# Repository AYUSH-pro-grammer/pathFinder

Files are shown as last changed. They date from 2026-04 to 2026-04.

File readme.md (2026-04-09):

# Pathfinder – Tiny Reaction Game!

Hello!! 
This is my Hack Club Stasis project  its based on reaction time and a bit of fun

---

## How It Works

- LEDs blink
- You press buttons 
- Turn the knob
- Try to react FAST!!

### Rules:
- Press button 1 -> led 1 lights up 
- Press button 2 -> quickly after btn1 -> builds combo both will get on
- if you press button 2 quickly and multiple times then led2 turns on
- Too slow? nothing happens

---

## Images

### 3D View
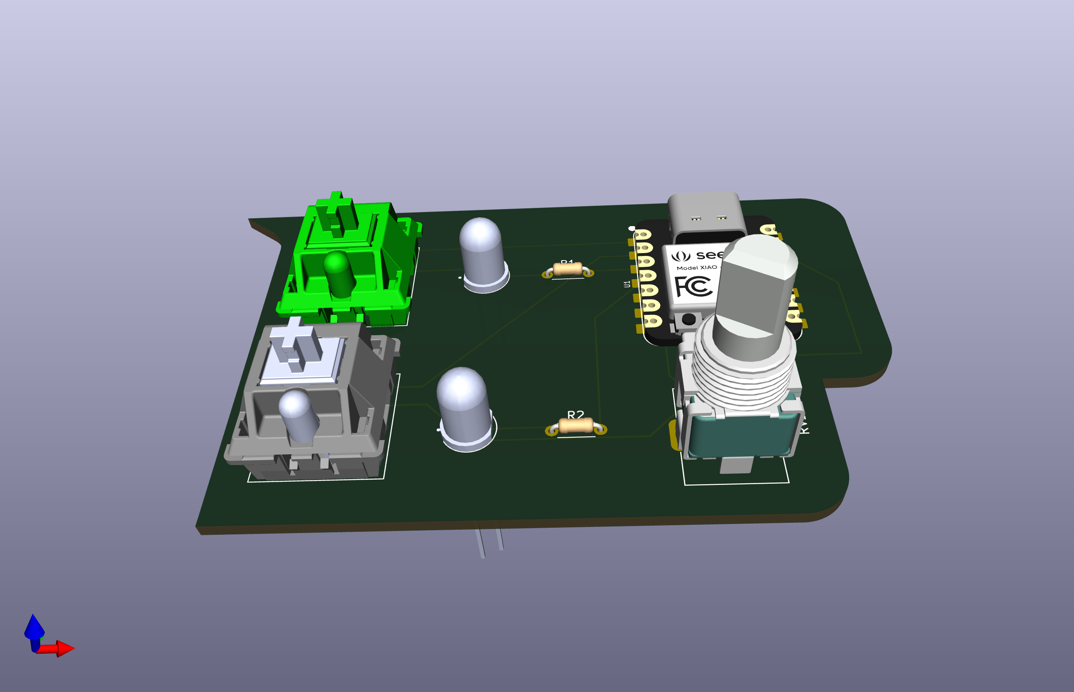
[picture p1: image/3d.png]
3D


### Circuit
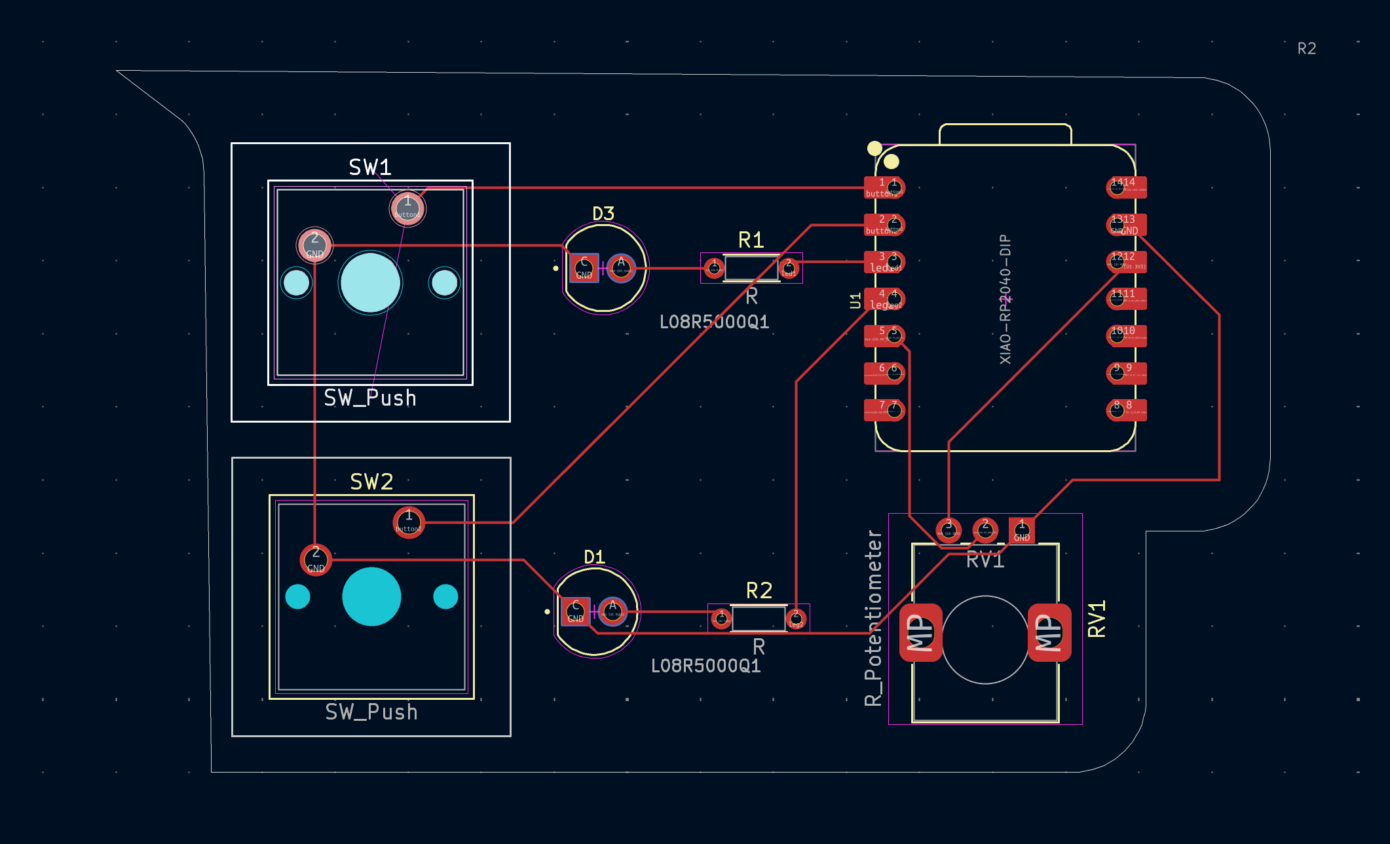
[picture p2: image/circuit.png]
Circuit


### Schematic
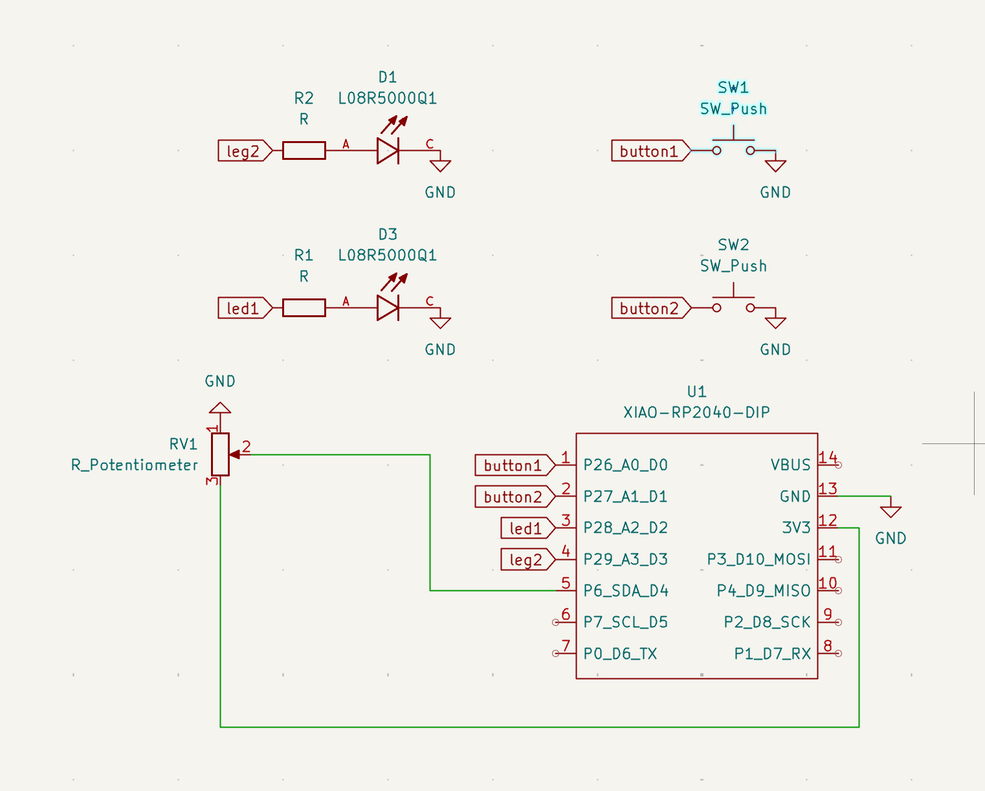
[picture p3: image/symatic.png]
Schematic


---

## Components

- LEDs 
- Resistors 
- Xiao RP2040 
- Cherry MX switches 
- PCB 
- Potentiometer (knob!!) 

---

## Code

```cpp
int btn1 = D0;
int btn2 = D1;
int led1 = D2;
int led2 = D3;

int potentio = D4;

long btn2cnt = 0;
long button1time = 0;
long button2time = 0;

void setup() {
  pinMode(btn1, INPUT_PULLUP);
  pinMode(btn2, INPUT_PULLUP);
  pinMode(potentio, INPUT);

  pinMode(led1, OUTPUT);
  pinMode(led2, OUTPUT);
}

void loop() {

  int pot_reading = analogRead(potentio);
  int brightness = map(pot_reading, 0, 1023, 0, 255);

  if (digitalRead(btn1) == LOW) {
    button1time = millis();
    analogWrite(led1, brightness);
  } else {
    analogWrite(led1, 0);
  }

  if (digitalRead(btn2) == LOW) {
    button2time = millis();
    btn2cnt += 1;
  }

  if (abs(button1time - button2time) <= 1000) {
    if (btn2cnt > 2) {
      analogWrite(led2, brightness);
      btn2cnt = 0;
    }
  } else {
    analogWrite(led2, 0);
  }
}

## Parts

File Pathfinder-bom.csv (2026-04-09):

Name | Purpose | Quantity | Total Cost (USD) | Link | Distributor
pcb | the main board where all compoents connects | 1 | 8.11 | https://jlcpcb.com/ | jlcpcb
LED Indication | it will glow | 2 | 0.10 | https://robu.in/product/tj-l5fytghgmcgsflc2g-a5-togialed-20ma-foggy-green-lens-20%e2%84%8380%e2%84%83-emerald-45-5mm-round-lamp-head-2-8v3-6v-plugind5mm-led-i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 | robu
Potentiometers | to increase and decrease the brightness of lights | 1 | 0.62 | https://robu.in/product/rk09k1130a5r-alpsalpine-%c2%b120-10k%cf%89-plugin-potentiometers-variable-resistors-rohs/ | robu
Seeed Studio XIAO RP2040 v1.0 | microcontroller controllers code | 1 | 7.00 | https://robu.in/product/seeed-studio-xiao-rp2040-v1-0/ | robu
Gateron Milky PRO Switch – 5pin | to send input to microcontroller | 1 | 3.50 | https://meckeys.com/cart/ | meckeys

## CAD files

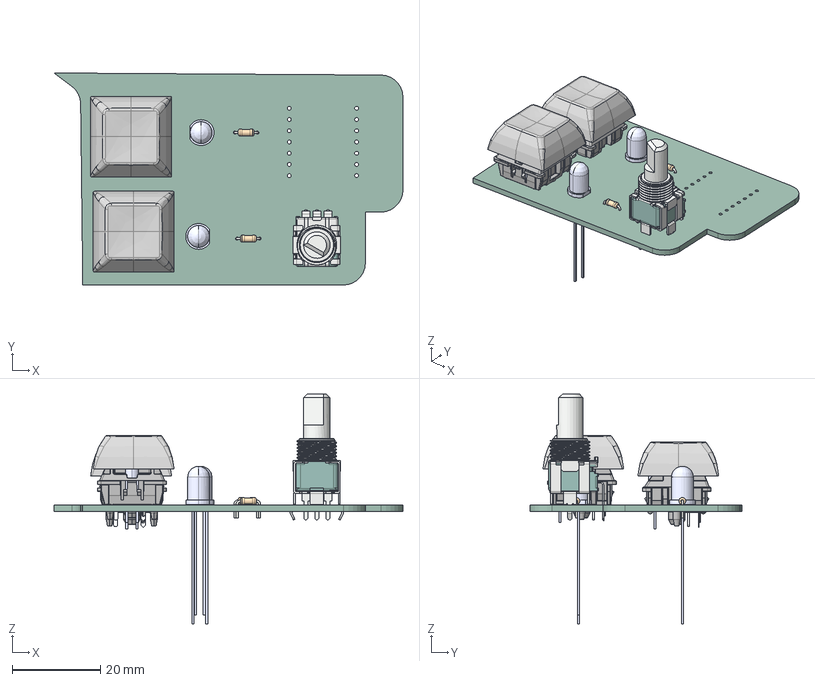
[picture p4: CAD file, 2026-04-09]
pathFinder.step
79.0 x 48.0 x 52.0 mm
RK09L1140-F15-C0
MX Öá °´¼ü¡ä_¨¹___¡§1 x 2
MX ס סͥ¨¢¨¬_¡§¡顧__ x 2
MXס ϞñLEDLEDLED x 2
MXÖá ÖáÌå µ×²¿ ¦Ì¡Á2__Ä¬ÈÏ_¨¢2____¨¨_ x 2
֫½ğ__Ĭɏ__¨¨_ x 2
DSA_Keycap_CherryMX x 2
R_Axial_DIN0204_L3.6mm_D1.6mm_P5.08mm_Horizontal x 2
Blue_LED_5mm_STEP x 2
pathFinder_PCB

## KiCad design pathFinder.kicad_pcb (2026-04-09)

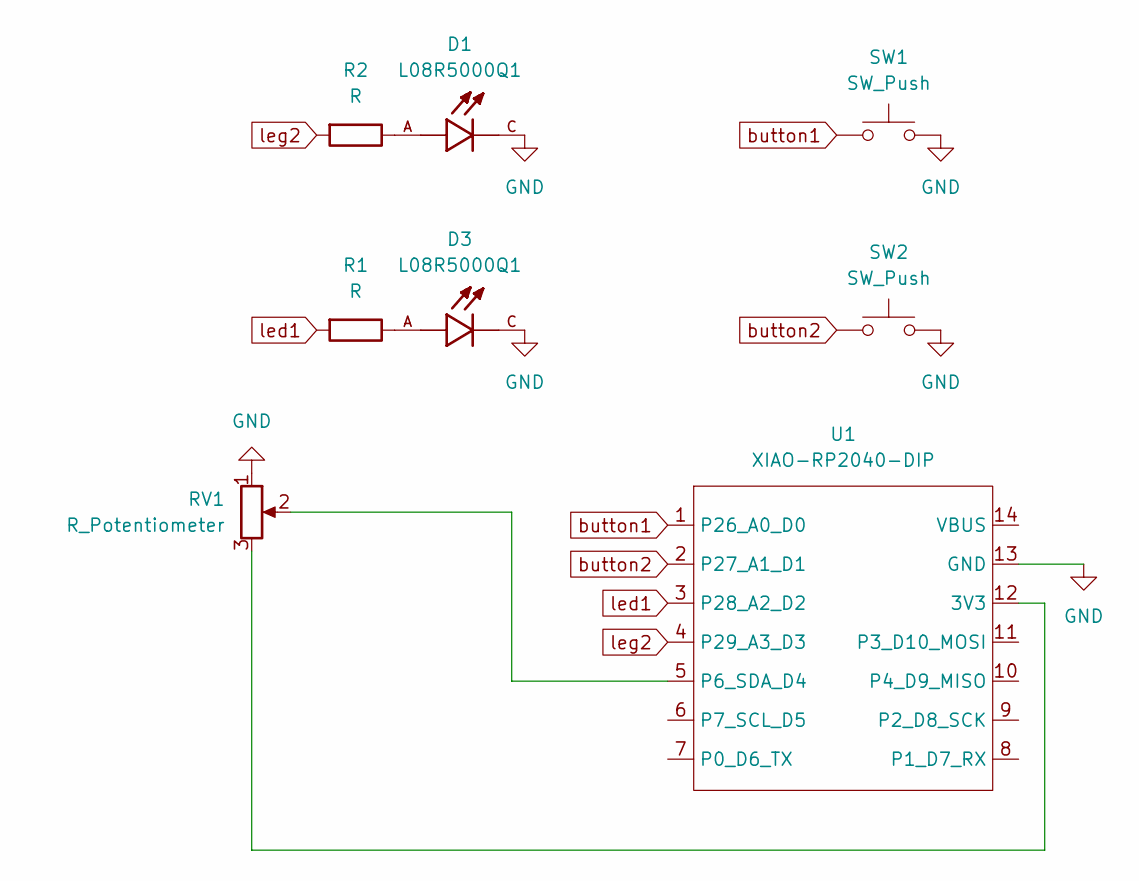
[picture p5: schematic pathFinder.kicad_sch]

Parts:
D1, D3: L08R5000Q1; LEDRD254W57D500H1070; PARTREV NA
R1, R2: R; R_Axial_DIN0204_L3.6mm_D1.6mm_P5.08mm_Horizontal
RV1: R_Potentiometer; Potentiometer_Alps_RK09K_Single_Vertical
SW1, SW2: SW_Push; SW_Cherry_MX_1.00u_PCB
U1: XIAO-RP2040-DIP

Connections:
GND: D1.C, D3.C, RV1.1, SW1.2, SW2.2, U1.13 (GND)
unnamed: D1.A, R2.1
unnamed: D3.A, R1.1
unnamed: RV1.3, U1.12 (3V3)
unnamed: RV1.2, U1.5 (P6_SDA_D4)
button1: SW1.1, U1.1 (P26_A0_D0)
button2: SW2.1, U1.2 (P27_A1_D1)
led1: R1.2, U1.3 (P28_A2_D2)
leg2: R2.2, U1.4 (P29_A3_D3)

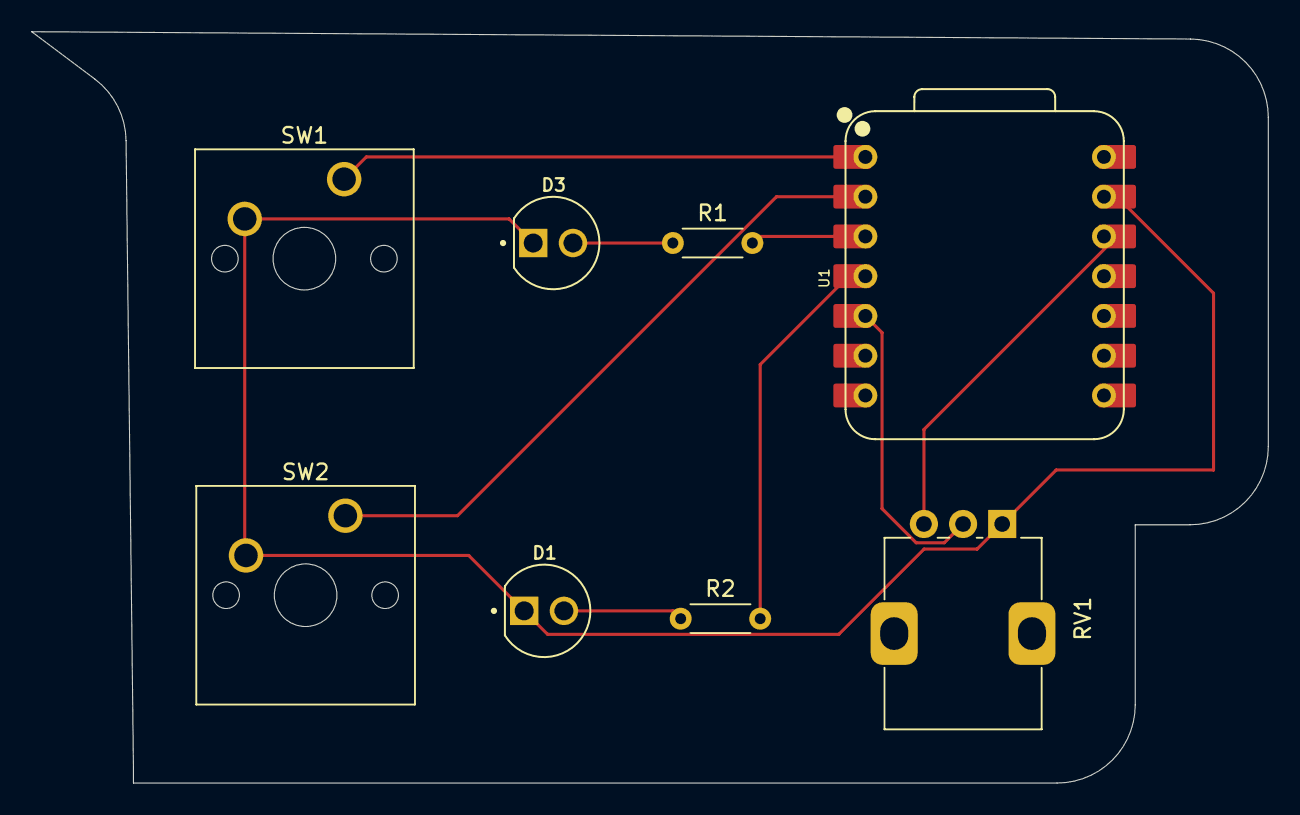
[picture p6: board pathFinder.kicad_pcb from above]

Board: 2 copper layers, 79.0 x 48.0 mm, 8 parts (0 on the bottom side), 9 nets.
